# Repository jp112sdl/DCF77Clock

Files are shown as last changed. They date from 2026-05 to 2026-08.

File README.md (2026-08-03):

# DCF77 Clock

Arduino-Uhr, die das DCF77-Zeitsignal dekodiert und auf einem TFT-Display
sowie einem NeoPixel-LED-Ring anzeigt.

## Funktion

- Liest das DCF77-Empfängersignal an `DCF_PIN` (D3) bit-genau über die
  Breite des Absenkimpulses (~100 ms = Bit 0, ~200 ms = Bit 1), gemessen an
  der fallenden Flanke. Dadurch leuchtet jede Sekunden-LED unmittelbar zu
  ihrer Sekunde – auch Bit 58 wird regulär erfasst.
- Erkennt den Minutenwechsel an der fehlenden 59. Sekundenmarke
  (Trägerphase > 1700 ms).
- Dekodiert Minute, Stunde, Tag, Wochentag, Monat, Jahr sowie die Status-Bits
  MEZ/MESZ, Schaltsekunde und Rufbit.
- Prüft die drei DCF77-Paritätsbits (Minute, Stunde, Datum) sowie die festen
  Rahmenbits (Bit 0 = 0, Bit 20 = 1). Nur bei korrekter Parität, plausiblen
  Werten und Jahr > 2025 wird die Zeit übernommen.
- Hält die Zeit per `RTC_Millis` (Software-RTC) zwischen den Synchronisationen.
- Löscht den Sekundenring, sobald der Sync verloren geht. Ein dauerhaft hell
  stehender Ring würde durch Laststrom und Störstrahlung verhindern, dass die
  Minutenmarke wieder erkannt wird.

## Anzeige

**TFT (ST7789, 76×284, SPI):** Datum + Uhrzeit, gerendert mit
`U8g2_for_Adafruit_GFX`. Vor erstem Sync: „Warte auf Uhrzeit". Die Anzeige
läuft nach dem ersten Sync frei aus der `RTC_Millis` weiter (Neuzeichnen bei
jedem Minutenwechsel) und bleibt damit auch bei gestörtem Empfang aktuell.

**NeoPixel-Ring (72× WS2812x an D6):**

| LEDs | Bedeutung |
|---|---|
| 0–59 | Sekunden-/Bitring, farbcodiert nach DCF77-Bitgruppe  |
| 60–67  | Wochentag (Mo–So) |
| 68 | Sync-Status (rot = kein Sync, grün = Sync) |
| 69 | MESZ (CEST) |
| 70 | MEZ (CET) |
| 71 | Schaltsekunde (Leap) |

## Hardware / Pins

| Pin | Funktion |
|---|---|
| D3 | DCF77-Signal |
| A3 | Status-Ausgang (Signal-LED)|
| D6 | NeoPixel-Daten |
| D8/D9/D10 | TFT RST / DC / CS |

Board: **Arduino Nano (AVR)** · Verkabelung siehe `Verkabelungsdiagramm.png`/`.svg`.

## Bibliotheken

RTClib · Adafruit GFX · Adafruit ST7789 · Adafruit BusIO ·
U8g2_for_Adafruit_GFX · NeoPixelBus

## Build

Kompilierung wird per GitHub Action (`.github/workflows/compile.yml`) bei
jedem Push automatisch geprüft.

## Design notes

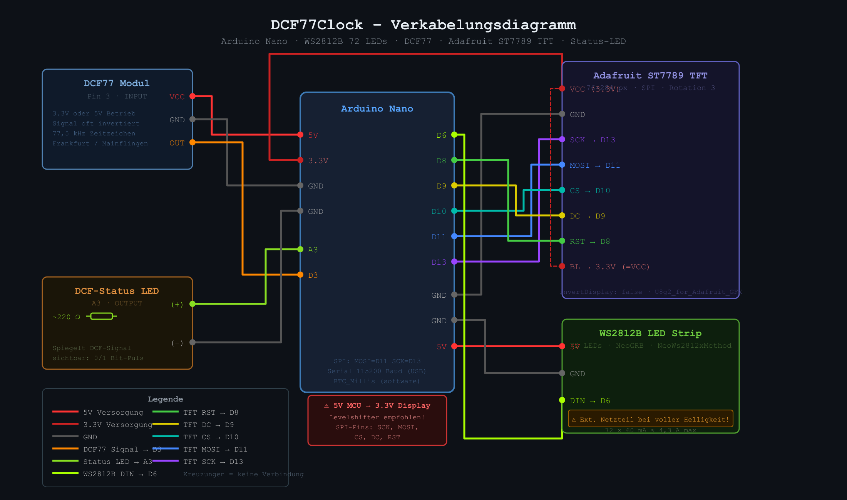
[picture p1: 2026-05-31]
Verkabelungsdiagramm.png

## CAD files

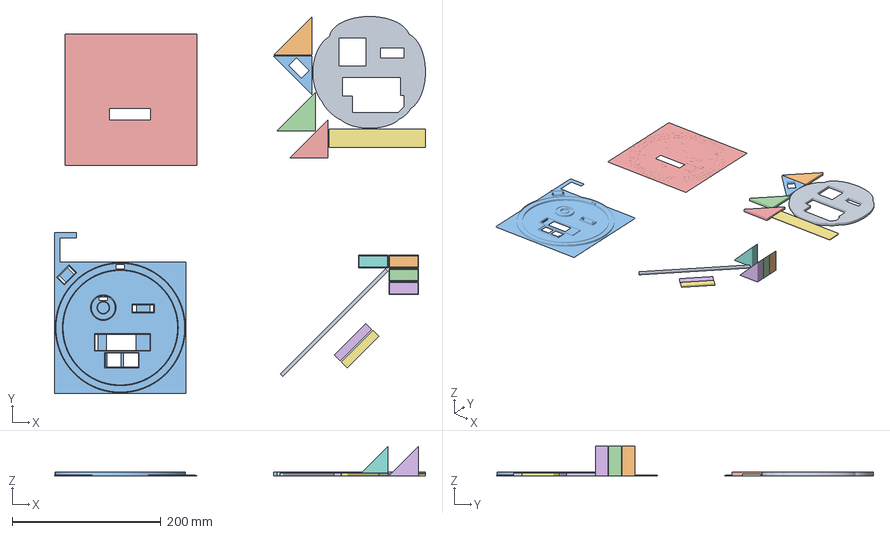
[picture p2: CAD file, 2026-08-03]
DCF77 Uhr.3mf
498.7 x 506.9 x 40.0 mm
DCF77 Uhr-7.stl
DCF77 Uhr-2.stl x 4
DCF77 Uhr-9.stl
DCF77 Uhr.stl x 4
DCF77 Uhr 07.01.34.stl
DCF77 Uhr-6.stl x 3
DCF77 Uhr-5.stl

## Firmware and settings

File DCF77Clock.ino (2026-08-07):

#include <RTClib.h>
#include <Adafruit_I2CDevice.h>
#include <Adafruit_GFX.h>
#include <Adafruit_ST7789.h>
#include <U8g2_for_Adafruit_GFX.h>
#include <NeoPixelBus.h>

#define DCF_PIN 3
#define STATUS_PIN A3
#define LED_PIN 6

#define TFT_RST 8
#define TFT_DC 9
#define TFT_CS 10

#define colorSaturation (uint8_t)255

// LED-Belegung des NeoPixel-Rings
#define LED_COUNT 72
#define LED_RING 60        // Sekunden-/Bitring, LEDs 0..59
#define LED_DOW_START 60   // Wochentag, LEDs 60..67
#define LED_SYNC 68        // Sync-Status (rot = kein Sync, gruen = Sync)
#define LED_CEST 69        // MESZ
#define LED_CET 70         // MEZ
#define LED_LEAP 71        // Schaltsekunde

// Hoechster im Frame verwendeter Bit-Index ist 58 (Paritaet Datum);
// +1 fuer den Index, +ein Reservebit fuer einen verpassten Minutenwechsel.
#define ZEIT_SIZE 61


Adafruit_ST7789 tft = Adafruit_ST7789(TFT_CS, TFT_DC, TFT_RST);
U8G2_FOR_ADAFRUIT_GFX u8g2;

NeoPixelBus<NeoGrbFeature, NeoWs2812xMethod> strip(LED_COUNT, LED_PIN);

RTC_Millis rtc;

unsigned long LOW_Start = 0;   // Beginn der aktuellen Traegerphase (LOW)
unsigned long LOW_Zeit = 0;    // Laenge der zuletzt beendeten Traegerphase
unsigned long HIGH_Start = 0;  // Beginn des aktuellen Absenkimpulses (HIGH)
unsigned long HIGH_Zeit = 0;   // Laenge des zuletzt beendeten Absenkimpulses

bool Signal = false;
bool DCF_SYNC = false;
bool DCF_SYNC_LAST = false;
bool LED59_shown = false;
int8_t BIT = -1;
uint8_t ZEIT[ZEIT_SIZE];

bool TIME_VALID = false;             // true, sobald einmal erfolgreich synchronisiert
uint8_t SHOWN_MINUTE = 0xFF;         // zuletzt auf dem TFT dargestellte Minute
unsigned long lastDisplayCheck = 0;  // Drossel fuer updateDisplay()


void setup() {
  Serial.begin(115200);

  pinMode(DCF_PIN, INPUT);
  pinMode(STATUS_PIN, OUTPUT);
  digitalWrite(STATUS_PIN, HIGH);

  tft.init(76, 284);
  tft.invertDisplay(false);
  tft.setRotation(3);
  tft.setTextColor(ST77XX_WHITE);
  u8g2.begin(tft);

  u8g2.setFontMode(1);
  u8g2.setFontDirection(0);
  u8g2.setForegroundColor(ST77XX_WHITE);
  u8g2.setFont(u8g2_font_inb16_mr);  // select u8g2 font from here: https://github.com/olikraus/u8g2/wiki/fntlistall

  tft.fillScreen(ST77XX_BLACK);

  u8g2.setCursor(10, 30);
  u8g2.print("Arduino DCF77 Clock");
  u8g2.setCursor(10, 60);
  u8g2.print(" Warte auf Uhrzeit");

  strip.Begin();  // Initialize NeoPixel object

  for (uint8_t i = 0; i < LED_COUNT; i++) {
    strip.SetPixelColor(i, { 16, 16, 16 });
  }
  strip.Show();
  delay(500);
  for (uint8_t i = 0; i < LED_COUNT; i++) {
    strip.SetPixelColor(i, { 0, 0, 0 });
  }

  strip.SetPixelColor(LED_SYNC, { colorSaturation, 0, 0 });
  strip.Show();

  rtc.adjust(DateTime(2000, 1, 1, 0, 0, 0));

  //Serial.println("Synchronisierung");
  digitalWrite(STATUS_PIN, LOW);
}

// Setzt eine LED auf 'color', wenn 'on', sonst aus.
void setOnOffLED(uint16_t idx, bool on, RgbColor color) {
  strip.SetPixelColor(idx, on ? color : RgbColor(0, 0, 0));
}

void setSyncLED() {
  if (DCF_SYNC != DCF_SYNC_LAST) {
    DCF_SYNC_LAST = DCF_SYNC;
    strip.SetPixelColor(LED_SYNC, DCF_SYNC ? RgbColor(0, colorSaturation, 0) : RgbColor(colorSaturation, 0, 0));

    // Beim Sync-Verlust den Sekundenring loeschen. Solange kein Sync besteht,
    // schreibt niemand mehr LED 0..59 - der Ring bliebe sonst dauerhaft hell
    // stehen. Die zusaetzliche Last/Stoerstrahlung verhindert dann, dass die
    // Minutenmarke wieder sauber erkannt wird: Der Sync kaeme nie zurueck.
    if (DCF_SYNC == false) {
      for (uint8_t i = 0; i < LED_RING; i++) strip.SetPixelColor(i, RgbColor(0, 0, 0));
    }

    strip.Show();
  }
}

void setCESTLED(uint8_t on) {
  setOnOffLED(LED_CEST, on, RgbColor(0, colorSaturation, 0));
}
void setCETLED(uint8_t on) {
  setOnOffLED(LED_CET, on, RgbColor(0, colorSaturation, 0));
}

void setLEAPLED(uint8_t on) {
  setOnOffLED(LED_LEAP, on, RgbColor(0, colorSaturation, 0));
}

void setDayOfWeekLED(uint8_t dayOfWeek) {
  for (uint8_t d = 0; d < 8; d++) {
    setOnOffLED(LED_DOW_START + d, dayOfWeek - 1  == d, RgbColor(colorSaturation, colorSaturation, 0));
  }
}

void setLedRing60Bit(uint8_t bit, bool on) {
  uint8_t r = 0;
  uint8_t g = 0;
  uint8_t b = 0;
  switch (bit) {
    case 0:
      for (uint8_t i = 0; i < LED_RING; i++) strip.SetPixelColor(i, { 0, 0, 0 });
      break;
    case 1 ... 14:
      if (on) b = colorSaturation;
      break;
    case 15 ... 19:
      if (on) r = colorSaturation;
      break;
    case 20:
      if (on) g = colorSaturation;
      break;
    case 21 ... 27:
      if (on) r = colorSaturation;
      break;
    case 28:
      if (on) {
        r = colorSaturation;
        b = colorSaturation;
      }
      break;
    case 29 ... 34:
      if (on) r = colorSaturation;
      break;
    case 35:
      if (on) {
        r = colorSaturation;
        b = colorSaturation;
      }
      break;
    case 36 ... 41:
      if (on) {
        r = colorSaturation;
        g = colorSaturation / 8;
      }
      break;
    case 42 ... 44:
      if (on) {
        b = colorSaturation;
        g = colorSaturation;
      }
      break;
    case 45 ... 49:
      if (on) {
        b = colorSaturation;
        g = colorSaturation;
      }
      break;
    case 50 ... 57:
      if (on) {
        b = colorSaturation;
        g = colorSaturation;
      }
      break;
    case 58:
      if (on) {
        r = colorSaturation;
        b = colorSaturation;
      }
      break;
  }


  if (r == 0 && g == 0 && b == 0) {
  //  r = 2;
  //  g = 2;
  //  b = 2;
  }

  strip.SetPixelColor(bit, { r, g, b });
}

void loop() {
  if (BIT > 58) { DCF_SYNC = false; }
  setSyncLED();
  uint8_t DCF_SIGNAL = digitalRead(DCF_PIN);
  digitalWrite(STATUS_PIN, DCF_SIGNAL);

  // Steigende Flanke: Beginn eines Absenkimpulses = Ende der Traegerphase.
  if (DCF_SIGNAL == HIGH && Signal == false) {
    Signal = true;
    HIGH_Start = millis();
    LOW_Zeit = HIGH_Start - LOW_Start;  // Laenge der gerade beendeten Traegerphase

    if (LOW_Zeit >= 1700) {
      // Lange Traegerphase = fehlende 59. Sekundenmarke -> neue Minute.
      // Der zuvor empfangene Frame (ZEIT[0..58]) ist jetzt vollstaendig.
      NEUMINUTE();
      BIT = 0;
      DCF_SYNC = true;
      LED59_shown = false;
    } else if (DCF_SYNC == true) {
      BIT++;
    } else {
      //Serial.print(".");
    }
  }

  // Fallende Flanke: Ende des Absenkimpulses -> Bit aus der Impulsbreite lesen.
  else if (DCF_SIGNAL == LOW && Signal == true) {
    Signal = false;
    LOW_Start = millis();
    HIGH_Zeit = LOW_Start - HIGH_Start;  // Laenge des Absenkimpulses

    if (DCF_SYNC == true && BIT >= 0 && BIT <= 58) {
      PrintBeschreibung(BIT);
      ZEIT[BIT] = BIT_Zeit(HIGH_Zeit);
      setLedRing60Bit(BIT, ZEIT[BIT] == 1);
      //Serial.print(ZEIT[BIT]);
      if (ZEIT[BIT] > 1) {
        DCF_SYNC = false;
        BIT = -1;
      }
    }
    strip.Show();
  }

  // Sekunde 59 (Minutenmarke) hat keinen Impuls. Damit die LED nicht erst beim
  // Minutenwechsel erscheint, wird sie nach ~1 s anhaltendem Traeger gesetzt.
  if (DCF_SYNC == true && BIT == 58 && Signal == false && !LED59_shown
      && (millis() - LOW_Start) > 1000) {
    LED59_shown = true;
    setLedRing60Bit(59, 0);
    strip.Show();
  }

  updateDisplay();
}

// Dekodiert ein Bit aus der Breite des Absenkimpulses: ~100 ms = 0, ~200 ms = 1.
// Schwellwerte ggf. an den verwendeten Empfaenger anpassen.
uint8_t BIT_Zeit(unsigned long HIGH_Zeit) {
  if (HIGH_Zeit >= 50 && HIGH_Zeit <= 150) { return 0; }
  if (HIGH_Zeit > 150 && HIGH_Zeit <= 300) { return 1; }
  //Serial.print("X");
  //Serial.println(HIGH_Zeit, DEC);
  return 3;  // ungueltige Impulsbreite -> Sync verwerfen
}

// Erwartetes Even-Parity-Bit ueber ZEIT[from..to]:
// liefert 1, wenn die Anzahl gesetzter Bits ungerade ist.
uint8_t expectedParity(uint8_t from, uint8_t to) {
  uint8_t cnt = 0;
  for (uint8_t i = from; i < (to + 1); i++) {
    if (ZEIT[i] == 1) cnt++;
  }
  return (cnt % 2 != 0);
}

// Dekodiert 'count' BCD-Bits ab Index 'from' zu einem Dezimalwert.
uint16_t bcdDecode(uint8_t from, uint8_t count) {
  static const uint8_t weights[] = { 1, 2, 4, 8, 10, 20, 40, 80 };
  uint16_t value = 0;
  for (uint8_t i = 0; i < count; i++) {
    if (ZEIT[from + i] == 1) value += weights[i];
  }
  return value;
}

// Wird beim Minutenwechsel aufgerufen; ZEIT[0..58] enthaelt den kompletten,
// gerade abgeschlossenen Frame (inkl. regulaer gemessenem Bit 58).
void NEUMINUTE() {
  uint8_t ZEIT_STUNDE = bcdDecode(29, 6);
  uint8_t ZEIT_MINUTE = bcdDecode(21, 7);
  uint8_t ZEIT_TAG = bcdDecode(36, 6);
  uint8_t ZEIT_MONAT = bcdDecode(45, 5);
  uint16_t ZEIT_JAHR = 2000 + bcdDecode(50, 8);
  uint8_t ZEIT_WOCHENTAG = bcdDecode(42, 3);
  bool PAR_STUNDE = ZEIT[35] & 1;
  bool PAR_MINUTE = ZEIT[28] & 1;
  bool PAR_DATUM = ZEIT[58] & 1;
  uint8_t ZEIT_LEAP = ZEIT[16];
  uint8_t ZEIT_CEST = ZEIT[17];
  uint8_t ZEIT_CET = ZEIT[18];

  uint8_t PAR_ZEIT_MINUTE = expectedParity(21, 27);
  uint8_t PAR_ZEIT_STUNDE = expectedParity(29, 34);
  uint8_t PAR_ZEIT_DATUM = expectedParity(36, 57);

  // Rahmen-Plausibilitaet: Bit 0 ist immer 0, Bit 20 immer 1. Faellt ein
  // Impuls aus, wird die Traegerluecke ~1900 ms lang und faelschlich als
  // Minutenmarke erkannt - der Frame ist dann verschoben und faellt hier auf.
  if (ZEIT[0] != 0) return;
  if (ZEIT[20] != 1) return;

  // Nur uebernehmen, wenn alle Paritaeten stimmen ...
  if (PAR_ZEIT_MINUTE != PAR_MINUTE) return;
  if (PAR_ZEIT_STUNDE != PAR_STUNDE) return;
  if (PAR_ZEIT_DATUM != PAR_DATUM) return;
  if (ZEIT_JAHR <= 2025) return;

  // ... und die Werte plausibel sind.
  if (ZEIT_STUNDE > 23 || ZEIT_MINUTE > 59) return;
  if (ZEIT_TAG < 1 || ZEIT_TAG > 31) return;
  if (ZEIT_MONAT < 1 || ZEIT_MONAT > 12) return;
  if (ZEIT_WOCHENTAG < 1 || ZEIT_WOCHENTAG > 7) return;

  setDayOfWeekLED(ZEIT_WOCHENTAG);
  setCESTLED(ZEIT_CEST);
  setCETLED(ZEIT_CET);
  setLEAPLED(ZEIT_LEAP);
  rtc.adjust(DateTime(ZEIT_JAHR, ZEIT_MONAT, ZEIT_TAG, ZEIT_STUNDE, ZEIT_MINUTE, 0));
  TIME_VALID = true;
  // Gezeichnet wird in updateDisplay(); das laeuft auch ohne Empfang weiter.
}

// Zeichnet Datum und Uhrzeit aus der Software-RTC. Laeuft unabhaengig vom
// DCF77-Empfang, damit die Anzeige bei gestoertem Signal weiterlaeuft statt
// auf dem letzten erfolgreich dekodierten Frame stehen zu bleiben.
// Neu gezeichnet wird nur beim Minutenwechsel.
void updateDisplay() {
  if (TIME_VALID == false) return;

  // Nur ~4x pro Sekunde pruefen. rtc.now() rechnet mehrere Divisionen und
  // wuerde die Flankenmessung sonst unnoetig verlangsamen.
  if (millis() - lastDisplayCheck < 250) return;
  lastDisplayCheck = millis();

  DateTime now = rtc.now();
  if (now.minute() == SHOWN_MINUTE) return;
  SHOWN_MINUTE = now.minute();

  char bufDate[] = "DD.MM.YYYY";
  char bufTime[] = "hh:mm";

  // Alte Anzeige loeschen, damit keine Reste schmalerer Werte stehen bleiben.
  tft.fillScreen(ST77XX_BLACK);

  u8g2.setCursor(20, 35);
  u8g2.print("Datum: ");
  u8g2.print(now.toString(bufDate));
  u8g2.setCursor(20, 60);
  u8g2.print("Uhrzeit: ");
  u8g2.print(now.toString(bufTime));
}

void PrintBeschreibung(int BitNummer) {
  /*
  switch (BitNummer) {
    case 0: Serial.println("\n# START MINUTE (IMMER 0)"); break;
    case 1: Serial.println("\n# WETTERDATEN"); break;
    case 15: Serial.println("\n# RUFBIT"); break;
    case 16: Serial.println("\n# MEZ/MESZ"); break;
    case 17: Serial.println("\n# MESZ"); break;
    case 18: Serial.println("\n# MEZ"); break;
    case 19: Serial.println("\n# SCHALTSEKUNDE"); break;
    case 20: Serial.println("\n# BEGIN ZEITINFORMATION (IMMER 1)"); break;
    case 21: Serial.println("\n# MINUTEN"); break;
    case 28: Serial.println("\n# PARITAET MINUTE"); break;
    case 29: Serial.println("\n# STUNDE"); break;
    case 35: Serial.println("\n# PARITAET STUNDE"); break;
    case 36: Serial.println("\n# TAG"); break;
    case 42: Serial.println("\n# WOCHENTAG"); break;
    case 45: Serial.println("\n# MONAT"); break;
    case 50: Serial.println("\n# JAHR"); break;
    case 58: Serial.println("\n# PARITAET DATUM"); break;
  }
  */
}

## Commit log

2026-06-01 Refactor: Code-Qualität und Korrektheit verbessern
    - Datums-Parität aus ZEIT[58] statt aus der Länge der Minutenmarke ableiten
    - TFT bei jedem Update löschen (verhindert Geisterbilder schmalerer Werte)
    - LED-Indizes als benannte Konstanten (LED_SYNC, LED_CEST, ...)
    - BCD-Dekodierung in Helper-Funktion bcdDecode() zusammengefasst
    - NEUMINUTE() mit Guard-Clauses entschachtelt
    - Plausibilitätsprüfung für Stunde/Minute/Tag/Monat/Wochentag ergänzt
    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
2026-06-02 Fix: Bit 58 / Minutenmarke korrekt behandeln
    - PAR_DATUM wieder aus der Länge der Minutenmarke ableiten (ZEIT[58] ist im
    Trägermessverfahren nicht als eigener Impuls erfassbar). Behebt Regression,
    durch die die Datums-Parität immer fehlschlug.
    - Während der Minutenmarke (LOW_Zeit >= 1700) kein Bit dekodieren -> verhindert
    Grau-Aufblinken von LED 58 und falschen Sync-Abbruch an der steigenden Flanke.
    - LED 58 mit korrekter Farbe und LED 59 (Minutenmarke) beim Minutenwechsel
    setzen.
    [DCF77Clock.ino]
2026-06-02 Experiment: Bits aus Absenkimpuls-Breite statt Trägerphase dekodieren
    Misst die Breite des Absenkimpulses an der fallenden Flanke (~100 ms = 0,
    ~200 ms = 1) statt der vorausgehenden Trägerphase an der steigenden Flanke.
    Vorteile gegenüber dem bisherigen Verfahren:
    - Jede Sekunden-LED leuchtet unmittelbar zu ihrer Sekunde (kein ~1 s Versatz).
    - Bit 58 (Datums-Parität) wird regulär gemessen statt aus der Länge der
    Minutenmarke rekonstruiert.
    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
2026-07-19 fix LED Ring passend zur Frontplatte
    [DCF77Clock.ino]
2026-08-03 add housing design files
    [DCF77 Uhr.3mf]
2026-08-03 Fix: Dauerhafter Sync-Verlust und eingefrorene Anzeige
    Behebt, dass die Uhr nach einiger Zeit dauerhaft stehen bleibt und sich nur
    durch einen Reset wieder fängt.
    1. Sekundenring beim Sync-Verlust löschen (Kernursache)
    LED 0-59 werden ausschließlich unter DCF_SYNC == true geschrieben. Ging der
    Sync verloren, blieb der Ring mit seinem letzten Muster dauerhaft hell
    stehen. Laststrom und Störstrahlung blieben damit auf Maximum, sodass die
    Minutenmarke nicht mehr sauber erkannt wurde und der Sync nie zurückkam -
    nur ein Reset (der den Strip-Puffer leert) brach die Schleife auf.
    Der Ring wird jetzt beim Übergang nach 'kein Sync' gelöscht.
    2. Freilaufende Anzeige aus der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
    [DCF77Clock.ino]
2026-08-07 leds off
